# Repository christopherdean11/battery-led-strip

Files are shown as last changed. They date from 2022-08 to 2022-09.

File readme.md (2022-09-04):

# Battery Boost LED Strip Driver
This repo contains the Kicad project files for a PCB to boost a 4-AA battery bank up to 12V to drive an LED tape strip. 

## Goal
Deisgn a PCB to power a 12V LED strip in a closet that turns on when the door opens and off when the door closes, in an area where there are no outlets availble for wall power.

## LED Tape Strip
I selected this LED tape strip from HitLights, model number: `L0512V-401-1630-U`.
Some quick information about these LEDs:  
* 16.4ft long, can be cut to length every 2 inches
* Runs on 12V
* 24W to power the full strip. This works out to 2A for the full strip, or 20 mA per cuttable 2 inch segment
* 4000 K LED color (this felt like a good compromise for a closet between 2700 K or 3000 K which is a warm white, and 5000 K "daylight" which is usually a bit harsh for me)

## PCB Rev0
See [Rev0 Design Notes](BatteryLedStripDriver-R0/readme.md)  
Here is a gif demonstrating the circuit on a short strip of LEDs
PCB  

Here are some [ideas for a future revision](BatteryLedStripDriver-R0/readme.md#next-gen-ideas)

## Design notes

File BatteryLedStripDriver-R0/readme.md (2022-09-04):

# PCB Rev0
The first attempat at a PCB to boost 4-AA batteries to driver 12V LED strip.

Here is the board next to a AA battery.  
PCB  

## Design
See the [schematic print](Outputs/BatteryLedStripDriver.pdf). Key elements include:  
#### Boost converter
*  `TPS55340PWP` to boost ~6V (with new batteries) to 12V. Needed something with a high enough current limit on the power switch to support 1A out at a duty cycle of 4V->12V, plus wanted it in stock at JLCPCB. This one matched those criteria and had the added benefit of TI's WEBENCH tool support.
#### PWM signal generator
* 555 timer `TLC555xD` for optional PWM dimming, with potentiometer to set duty cycle. Here's an [article with 555 timer circuits](https://www.electronics-tutorials.ws/waveforms/555-circuits-part-1.html) that I referred to while adding this to the schematic. 
#### PMOS pass transistors
* `DMP2305U` to switch the boost converter and 555 timer input power on door open/close. Using PMOS because I didn't want to get into charge pumps to drive NMOS transistors. This one is rated for max Vds of -20V, max drain current of -4A, and Rdson of 60mΩ when pulling Vgs to -4.5V. 
#### Reed switch
* Found a [reed switch with both NC and NO options](https://www.amazon.com/dp/B073Z7TQ5D), which meant I couldn't mess up the order and get the wrong type :)
* This will be used to detect the door open/close state
* I added a small circuit to deal with the reed switch as NO or NC, selected by a jumper. This NC/NO combined switch was great for testing that circuit. 
#### Other Notes
* Some sections are tied together with 0 ohm resistors in case anything didn't work it could be excluded by removing a resistor instead of removing the whole IC. 
* I wasn't sure how well PWM-ing the boost converter output would work since it would effectively be seen as continuous load transients. Normally you would want to tie the EN pin of the DC/DC with the PWM signal, but this boost converter has an EN falling delay of 1ms before disabling, but it was hard enough to find this one to use, so I just went for it. I figured the lights would dim but the output voltage might be a bit ugly on the oscilloscope.
* Followed [Phil's Lab video](https://www.youtube.com/watch?v=C7-8nUU6e3E) on how to take a Kicad project to JLCPCB for fabrication and assembly. Some of the process is slightly updated since the video was made but it was easy enough to use, in fact the JLC website has a great in-browser experience for adjusting the part rotations that wasn't available at the time the video was filmed. 

## Bring up notes
#### Missing Pulldown
* Found a missed pulldown resistor on the gate of Q1 while reviewing the schematic again before the board arrived
  * This proved to in fact be an issue where the reed switch would not induce a state change unless it was probed with the oscilloscope, presumably adding a small leakage path to ground.  

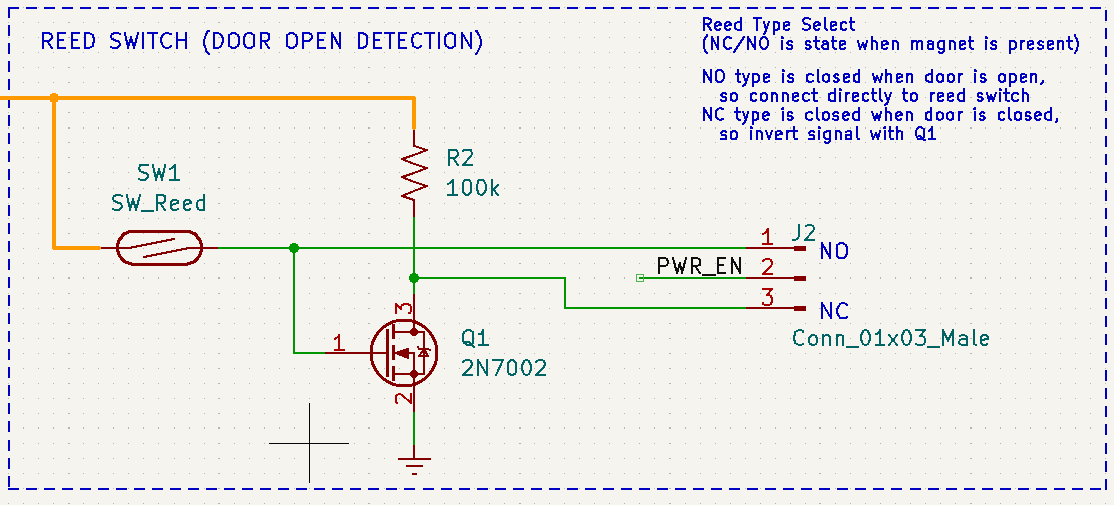
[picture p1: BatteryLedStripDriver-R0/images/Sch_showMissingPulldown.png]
      

  * Added 100k from Q1 gate (pin 1) to GND. I had a 100k through-hole on hand, so I tied it from SW1 pin 1 to the unmasked mounting hole, since the mounting holes were tied to GND (for easy oscillocope probe GND clip spots).   
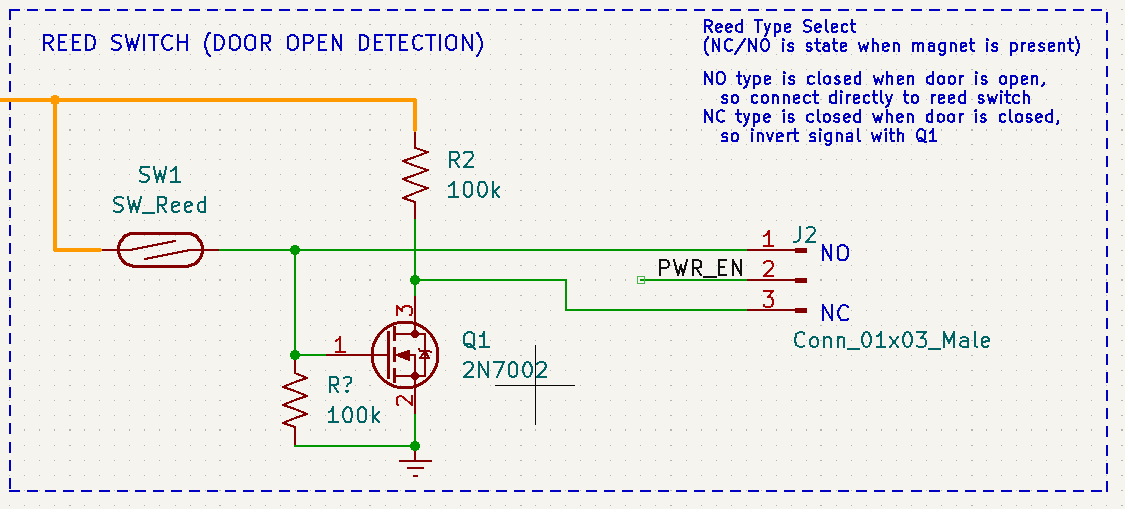
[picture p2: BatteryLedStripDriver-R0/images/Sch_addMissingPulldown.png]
        
    The net with the gate of Q1 is highlighted in the PCB image below, showing where the resistor was added between the SW1 jumper pin and GND pad of the mounting hole.

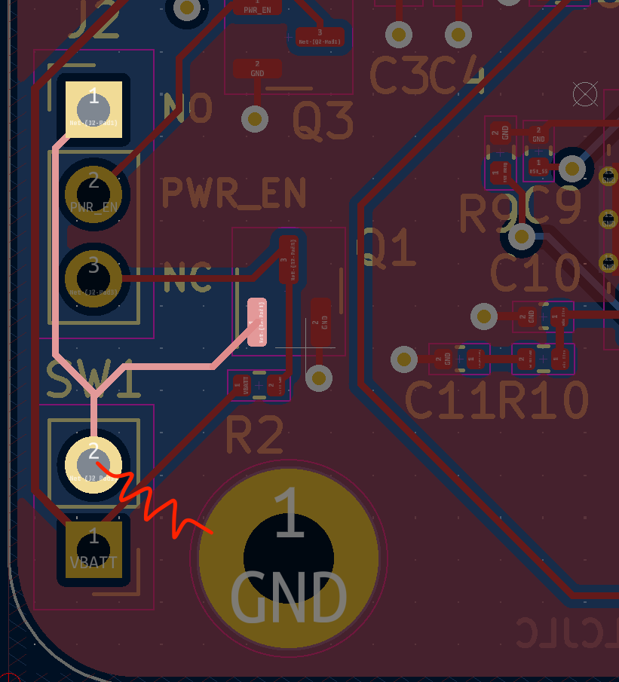
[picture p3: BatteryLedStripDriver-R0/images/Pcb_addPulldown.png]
      

  * :white_check_mark: With the pulldown in place the board turns on/off with the reed switch as desired! :) 
* All of the following test notes assume the Q1 pulldown is in place.

#### Enable
* :white_check_mark: Tested NO and NC enable modes (with the appropriate NO or NC reed switch connection), both turn on the output when the reed swith is opened/separated (i.e. the door is opened), so the invert/no-invert circuit works as desired. 
#### PWM
* Tested with two 1k resistors in parallel to get 12V/500ohm = 24mA load
* Can PWM up to 100% duty cycle and down to less than 5%
* Output waveform is not nice and square, has a 2.5-3V dip on PWM rising edge, likely because of the load transient caused by PWM-ing the load without disabling the power converter. 
* :white_check_mark: The LEDs can be dimmed from full brigthness down to almost off.

#### End-to-End Test
* :white_check_mark: Battery bank + PCB + short LED strip + Reed switch, works as desired :)
  PCB 

* :white_check_mark: Full test with battery bank and 2 ft. LED strip works!   
* There is an audible buzzing/humming when dimming the LEDs while drawing high current (longer strip) due to PWM-ing the output, and most likely [causing the cermaic output capacitors to vibrate against the PCB](https://www.murata.com/en-us/products/capacitor/ceramiccapacitor/library/apps/notepc) in the audio frequency band due to the low PWM frequency. Going to 100% duty cycle eliminates the noise. 

## Installation
Here it is installed above the door inside the previous very dark closet.  
  PCB  
I have 1980's textured ceiling/walls inside the closet, so I stuck the LED strip to the thinnest peice of wood I had on hand, zip-tied the battery holder and PCB to another peice of wood, and attched each with some screws into the drywall. 
The reed switch and magnet are mounted at the top of the doorway and the door. 

## Next-Gen Ideas
A few thoughts that came up to include for a next revision:
* Add an MCU 
  - More flexible PWM generation
  - Timer to shut off the lights if door is left open
  - Battery monitoring with some kind of indicator for low battery (such as blinking the LEDs once or twice at power-on)
* Different power converter
  - One that supports PWM-ing the EN pin. May need to try using a LED driver IC and 'trick' it into constant voltage mode 
  - Consider a buck-boost. This could allow for multiple output voltage levels for different LED strips. I've seen 5V and 6V strips as well as the typical 12V strip. Some go up to 24V but boosting 6V to 24V *and* getting near 1A out would be a lot of amps at the input. 
* I would love to get some kind of single, full enclosure solution
* Connectors instead of terminal jacks. Terminal jacks are great for protyping but not great for actual long-term installation.

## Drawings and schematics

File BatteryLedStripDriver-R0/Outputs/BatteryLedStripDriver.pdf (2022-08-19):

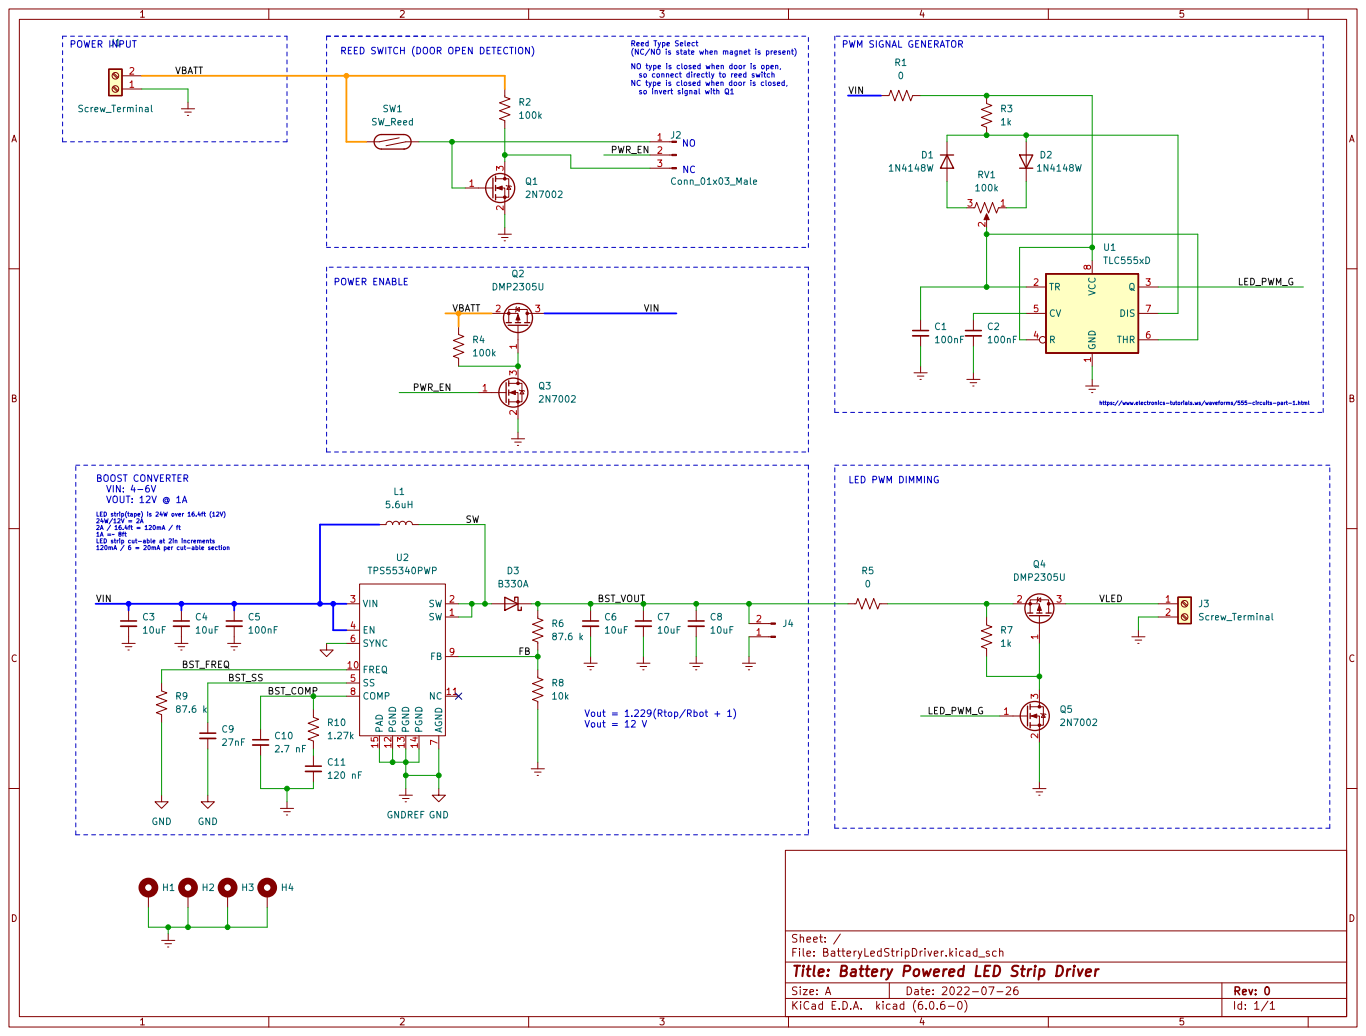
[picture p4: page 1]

Reed Type Select (NC/NO is state when magnet is present)

NO type is closed when door is open,
so connect directly to reed switch NC type is closed when door is closed,

so invert signal with Q1 POWER ENABLE

LED strip(tape) is 24W over 16.4ft (12V) 24W/12V = 2A 2A / 16.4ft = 120mA / ft 1A =~ 8ft LED strip cut-able at 2in increments 120mA / 6 = 20mA per cut-able section BOOST CONVERTER
VIN: 4-6V
VOUT: 12V @ 1A

Vout = 1.229(Rtop/Rbot + 1) Vout = 12 V

Id: 1/1 Title: Battery Powered LED Strip Driver

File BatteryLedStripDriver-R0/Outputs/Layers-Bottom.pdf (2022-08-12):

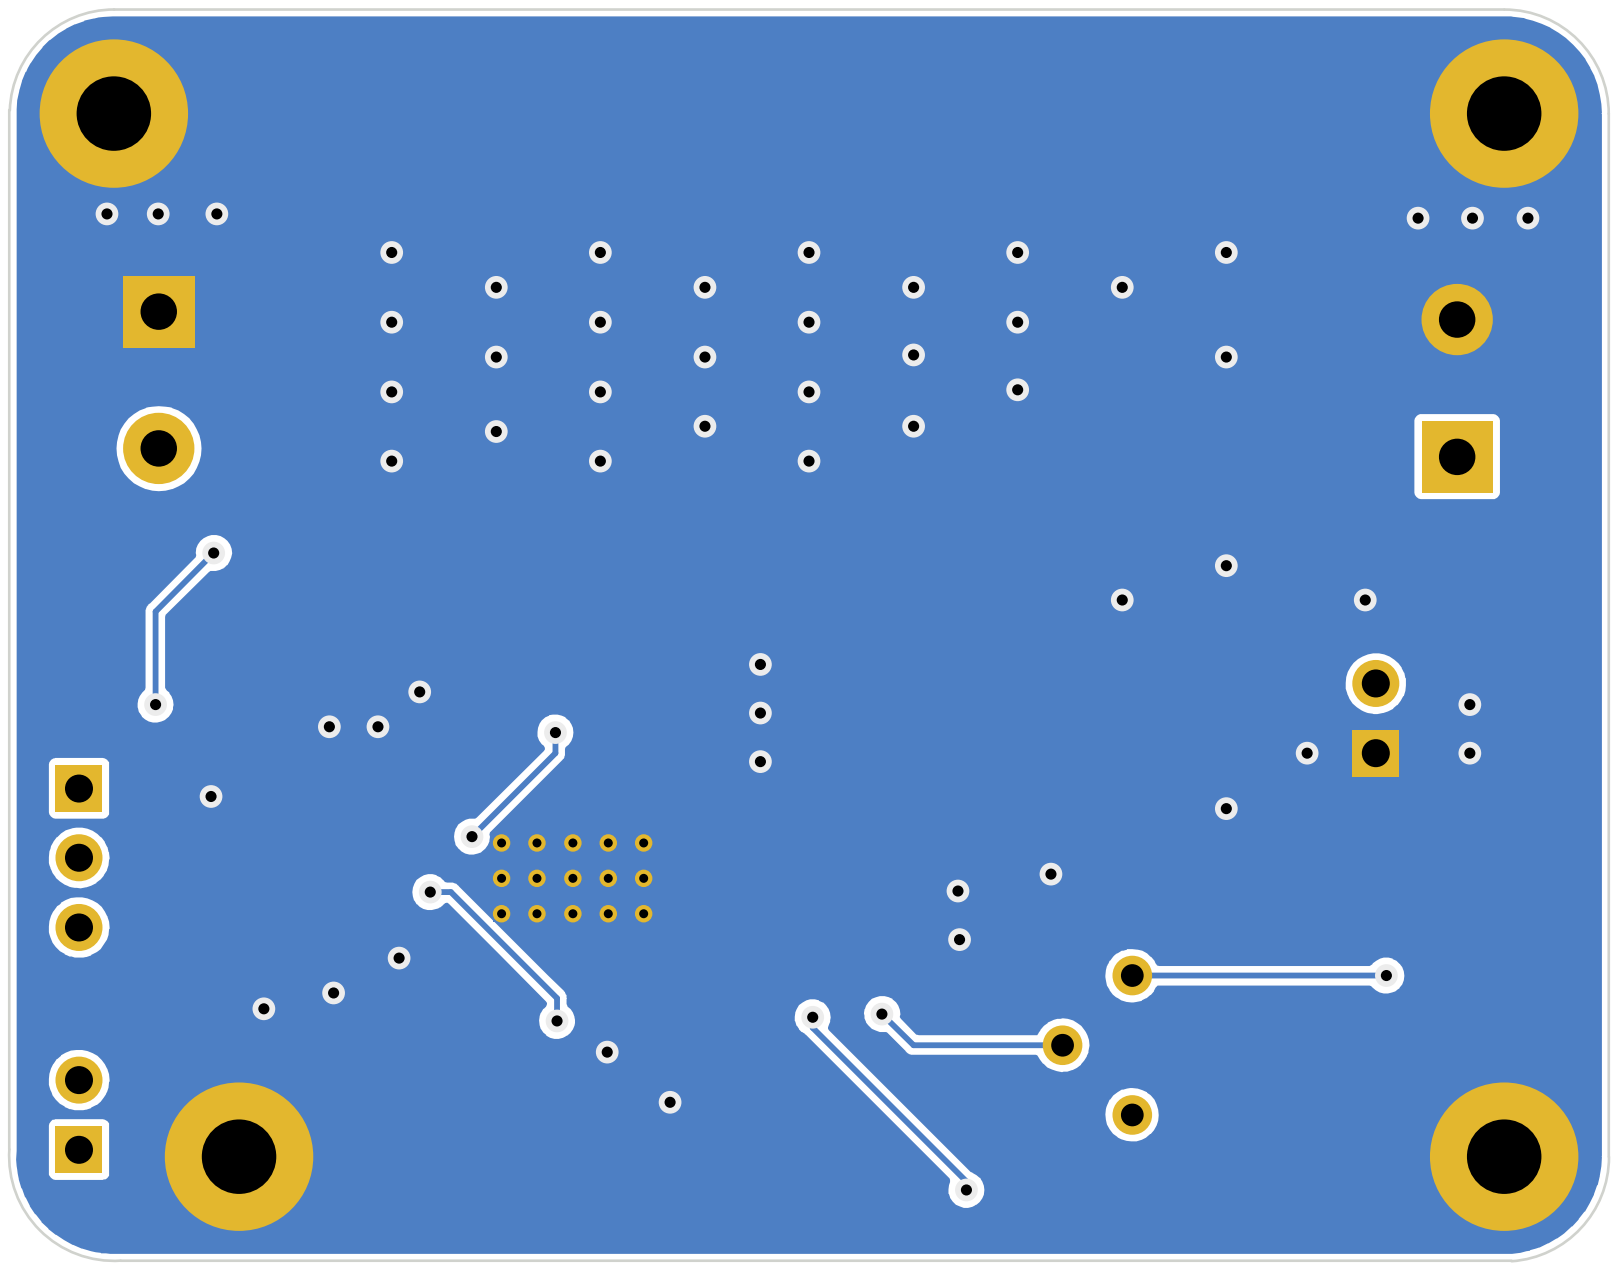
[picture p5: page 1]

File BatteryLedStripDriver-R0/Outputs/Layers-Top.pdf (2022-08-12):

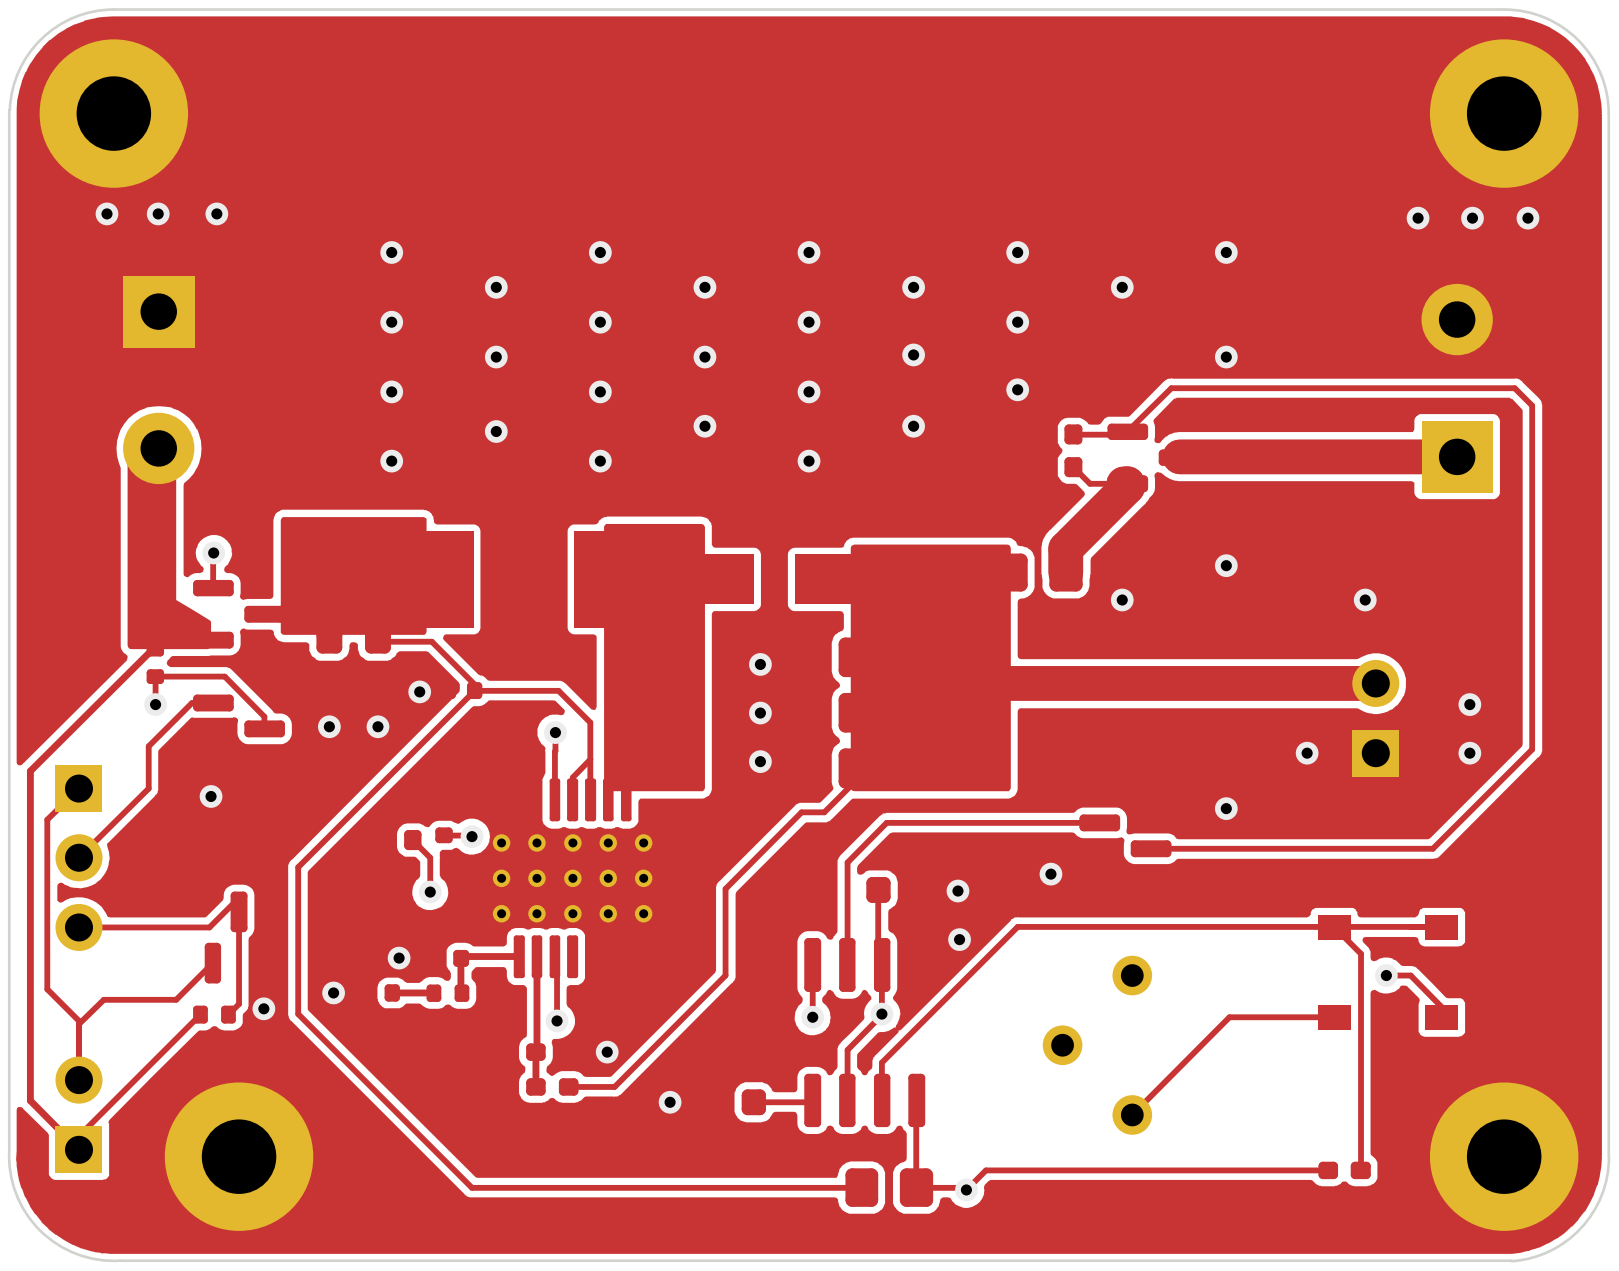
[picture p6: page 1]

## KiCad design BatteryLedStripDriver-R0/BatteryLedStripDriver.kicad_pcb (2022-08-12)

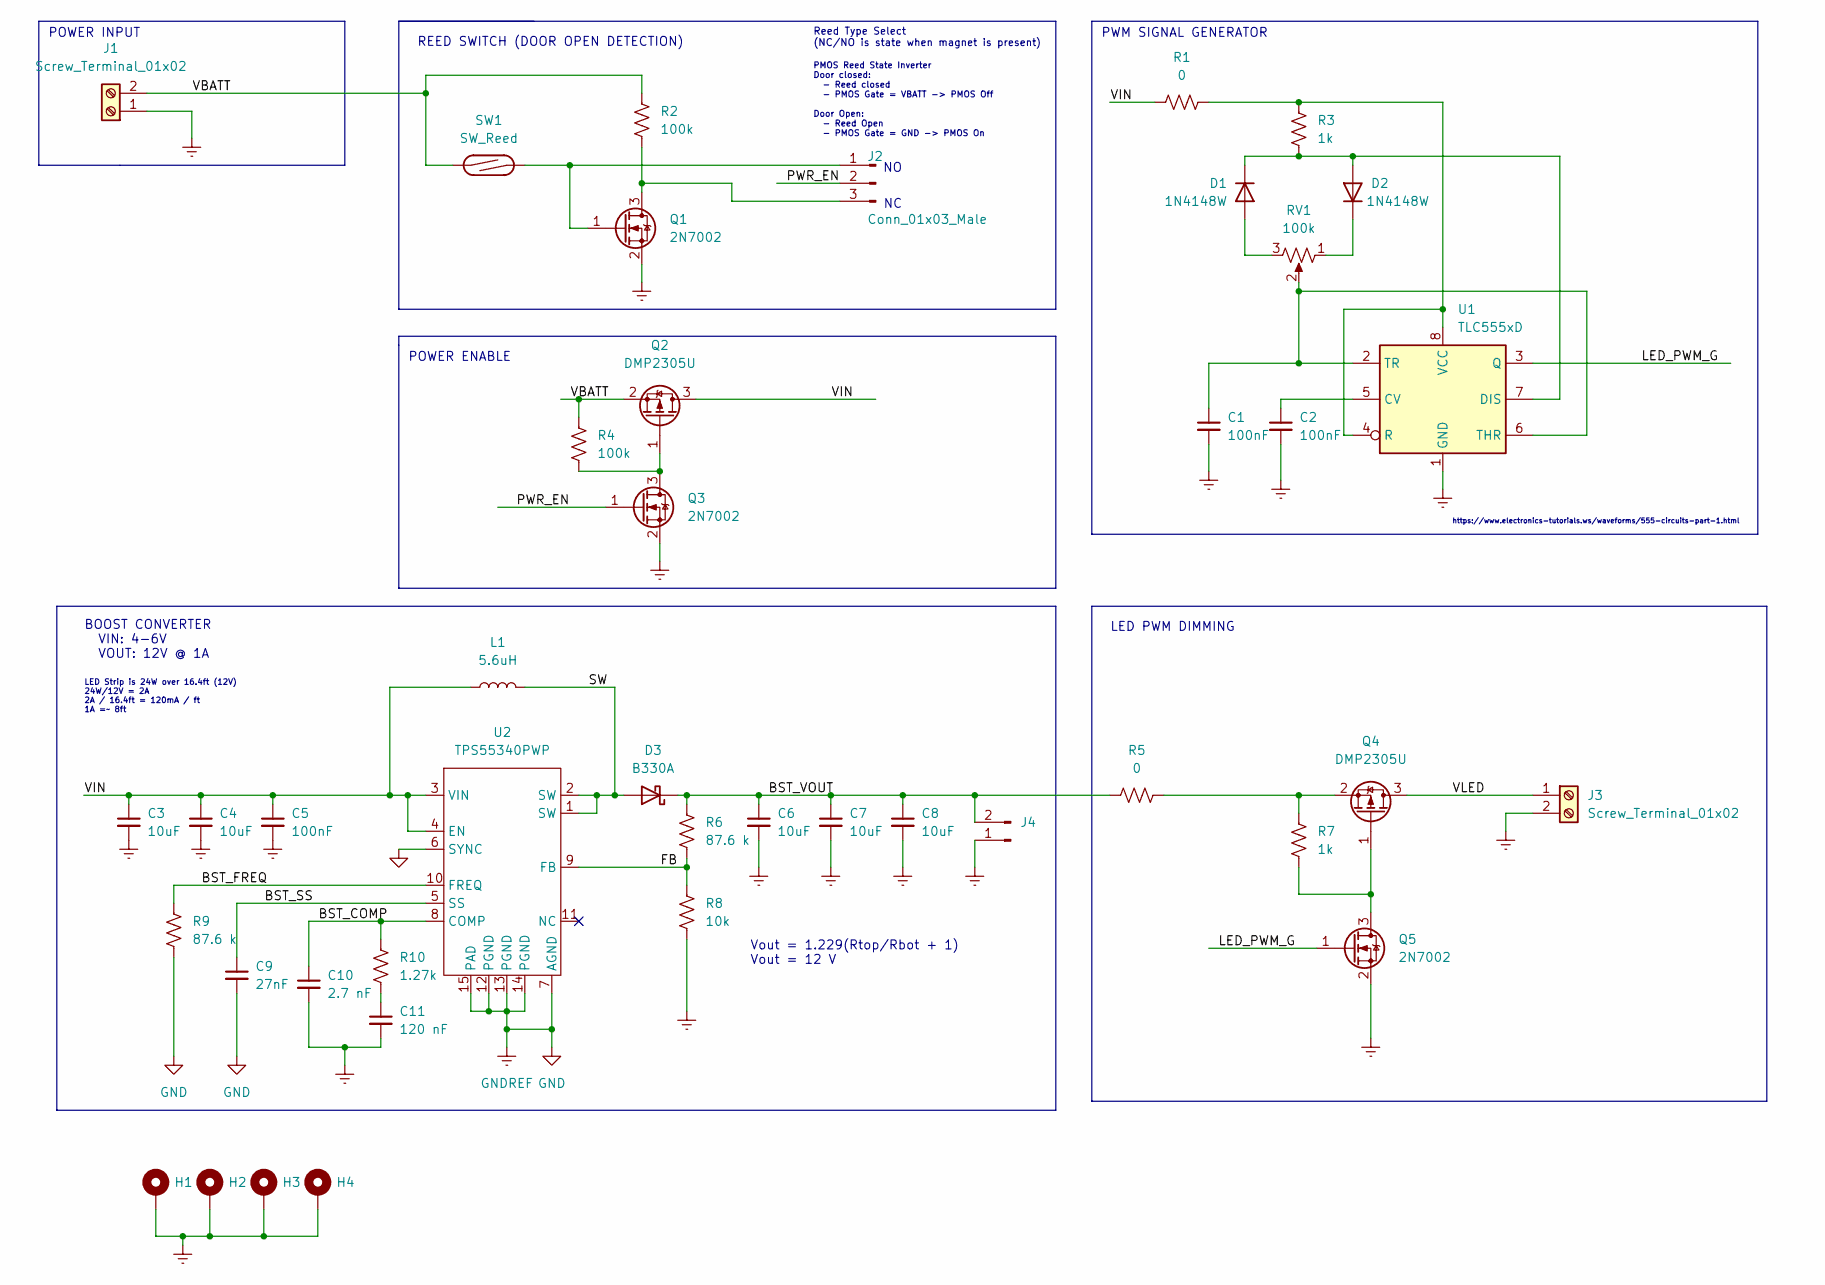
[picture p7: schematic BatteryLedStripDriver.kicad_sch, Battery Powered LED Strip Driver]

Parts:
C1, C2: 100nF; C_0603_1608Metric; LCSC Part # C14663
C3, C4: 10uF; C_0603_1608Metric; LCSC Part # C96446
C5: 100nF; C_0402_1005Metric; LCSC Part # C1525
C6, C7, C8: 10uF; C_0805_2012Metric; LCSC Part # C15850
C9: 27nF; C_0402_1005Metric; LCSC Part # C387951
C10: 2.7 nF; C_0402_1005Metric; LCSC Part # C387950
C11: 120 nF; C_0402_1005Metric; LCSC Part # C426033
D1, D2: 1N4148W; D_SOD-123; LCSC Part # C81598
D3: B330A; D_SMA; LCSC Part # C110485
H1, H2, H3, H4: MountingHole_Pad; MountingHole_2.7mm_M2.5_Pad
J1, J3: Screw_Terminal_01x02; TerminalBlock_Phoenix_MKDS-1,5-2_1x02_P5.00mm_Horizontal; LCSC Part # C474881
J2: Conn_01x03_Male; PinHeader_1x03_P2.54mm_Vertical
J4: Conn_01x02_Male; PinHeader_1x02_P2.54mm_Vertical
L1: 5.6uH; L_Sunlord_MWSA0603S_8.4x3.5mm; LCSC Part # C408448
Q1, Q3, Q5: 2N7002; SOT-23; LCSC Part # C8545
Q2, Q4: DMP2305U; SOT-23; LCSC Part # C85097
R1, R5: 0; R_0805_2012Metric_Pad1.20x1.40mm_HandSolder; LCSC Part # C17477
R2, R4: 100k; R_0402_1005Metric; LCSC Part # C25741
R3, R7: 1k; R_0402_1005Metric_Pad0.72x0.64mm_HandSolder; LCSC Part # C11702
R6, R9: 87.6 k; R_0402_1005Metric_Pad0.72x0.64mm_HandSolder; LCSC Part # C477808
R8: 10k; R_0402_1005Metric_Pad0.72x0.64mm_HandSolder; LCSC Part # C25744
R10: 1.27k; R_0402_1005Metric; LCSC Part # C327364
RV1: 100k; Potentiometer_Bourns_3386P_Vertical; LCSC Part # C118965
SW1: SW_Reed; PinHeader_1x02_P2.54mm_Vertical
U1: TLC555xD; SOIC-8_3.9x4.9mm_P1.27mm; LCSC Part # C6986
U2: TPS55340PWP; HTSSOP-14-1EP_4.4x5mm_P0.65mm_EP3.4x5mm_Mask3x3.1mm_Thermal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; LCSC Part # C43862

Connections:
/BST_COMP: C10.1, R10.1, U2.8 (COMP)
/BST_FREQ: R9.1, U2.10 (FREQ)
/BST_SS: C9.1, U2.5 (SS)
/BST_VOUT: C6.1, C7.1, C8.1, D3.1 (K), J4.2, R5.1, R6.1
/FB: R6.2, R8.1, U2.9 (FB)
/LED_PWM_G: Q5.1 (G), U1.3 (Q)
/PWR_EN: J2.2, Q3.1 (G)
/SW: D3.2 (A), L1.2, U2.1 (SW), U2.2 (SW)
/VBATT: J1.2, Q2.2 (S), R2.1, R4.1, SW1.1
/VIN: C3.1, C4.1, C5.1, L1.1, Q2.3 (D), R1.1, U2.3 (VIN), U2.4 (EN)
/VLED: J3.1, Q4.3 (D)
GND: C1.2, C2.2, C3.2, C4.2, C5.2, C6.2, C7.2, C8.2, C9.2, C10.2, C11.2, H1.1, H2.1, H3.1, H4.1, J1.1, J3.2, J4.1, Q1.2 (S), Q3.2 (S), Q5.2 (S), R8.2, R9.2, U1.1 (GND), U2.6 (SYNC), U2.7 (AGND), U2.12 (PGND), U2.13 (PGND), U2.14 (PGND), U2.15 (PAD)
unnamed: C1.1, RV1.2, U1.2 (TR), U1.6 (THR)
unnamed: C2.1, U1.5 (CV)
unnamed: C11.1, R10.2
unnamed: D1.1 (K), D2.2 (A), R3.2, U1.7 (DIS)
unnamed: D1.2 (A), RV1.3
unnamed: D2.1 (K), RV1.1
unnamed: J2.1, Q1.1 (G), SW1.2
unnamed: J2.3, Q1.3 (D), R2.2
unnamed: Q2.1 (G), Q3.3 (D), R4.2
unnamed: Q4.1 (G), Q5.3 (D), R7.2
unnamed: Q4.2 (S), R5.2, R7.1
unnamed: R1.2, R3.1, U1.4 (R), U1.8 (VCC)

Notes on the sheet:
PWM SIGNAL GENERATOR
POWER INPUT
Vout = 1.229(Rtop/Rbot + 1) Vout = 12 V
LED PWM DIMMING
Reed Type Select (NC/NO is state when magnet is present)
https://www.electronics-tutorials.ws/waveforms/555-circuits-part-1.html
LED Strip is 24W over 16.4ft (12V) 24W/12V = 2A 2A / 16.4ft = 120mA / ft 1A =~ 8ft
POWER ENABLE
REED SWITCH (DOOR OPEN DETECTION)
BOOST CONVERTER VIN: 4-6V VOUT: 12V @ 1A
PMOS Reed State Inverter Door closed: - Reed closed - PMOS Gate = VBATT -> PMOS Off Door Open: - Reed Open - PMOS Gate = GND -> PMOS On

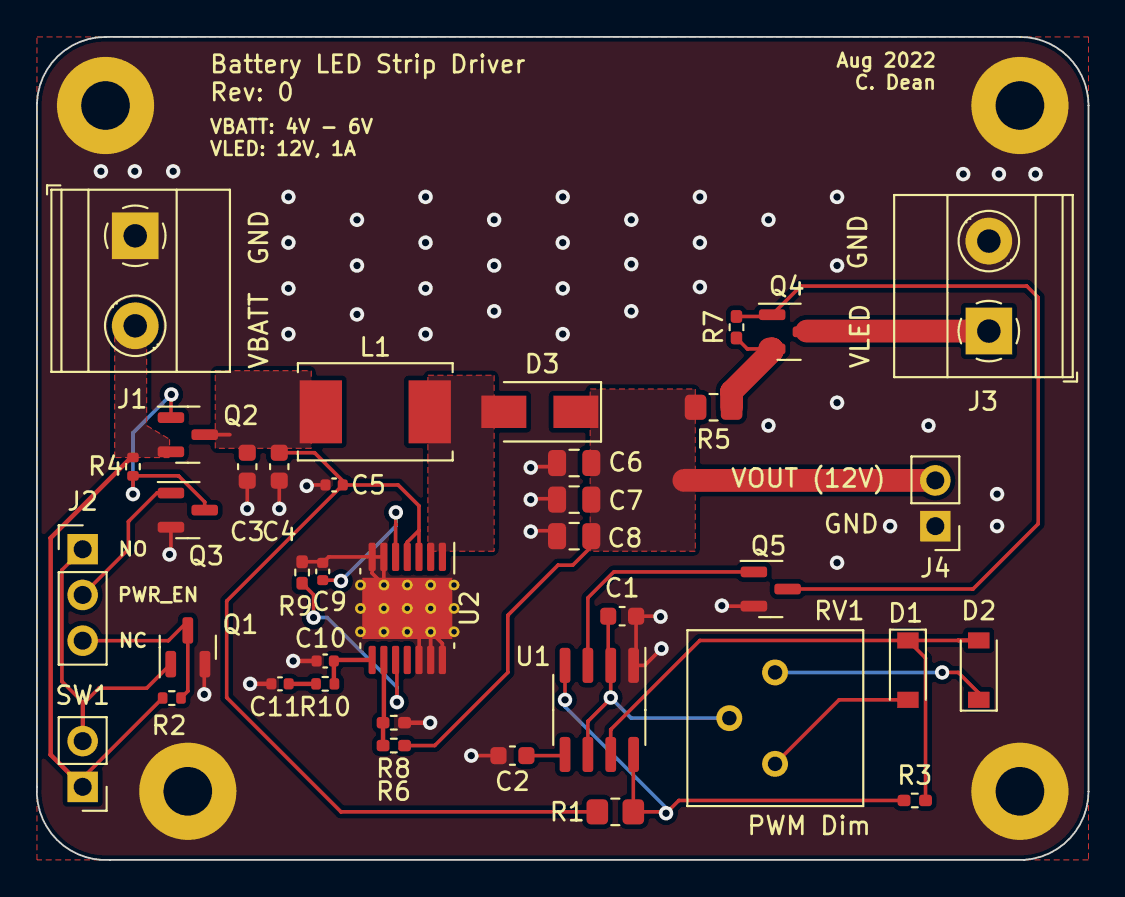
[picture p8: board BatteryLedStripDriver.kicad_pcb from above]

Board: 2 copper layers, 58.4 x 45.7 mm, 42 parts (0 on the bottom side), 24 nets.

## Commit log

2022-08-12 initial add of PCB as fabricated
    [BatteryLedStripDriver-B_Cu.gbr, BatteryLedStripDriver-B_Mask.gbr, BatteryLedStripDriver-B_Paste.gbr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]
2022-08-19 fix sch typos, add/update readmes
    [BatteryLedStripDriver.kicad_sch]
2022-08-19 add board image
